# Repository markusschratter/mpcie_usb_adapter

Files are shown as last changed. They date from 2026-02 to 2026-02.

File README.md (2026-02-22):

# mPCIe USB Adapter

The mPCIe USB Adapter enables connecting mPCIe modules (WiFi, Bluetooth, GNSS, etc.) to a host system via USB 2.0. The board features power regulation from 5V to 3.3V, comprehensive ESD protection on USB and signal lines, and RF connectors for antenna connections. Status LEDs provide visual feedback for power indication.

- mPCIe connector for module connection
- USB 2.0 Type-C connector for host connectivity
- 3.3V voltage regulator (LD1117S33TR) for power regulation
- ESD protection diodes for USB and signal lines
- Status LEDs (Kingbright AA4040SURSK) for power indication
- SMA connectors for RF/antenna connections
- Coaxial connectors for additional RF connections

## Overview

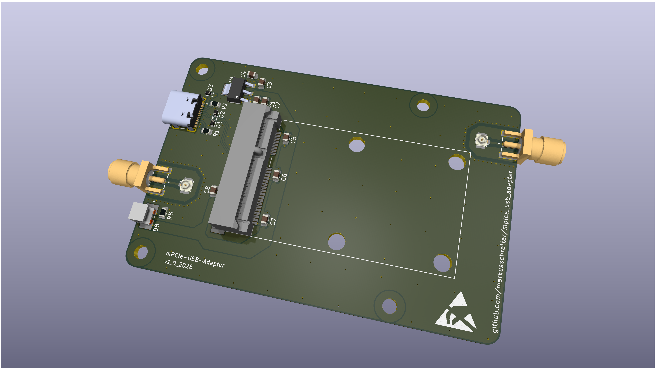
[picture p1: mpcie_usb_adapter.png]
mPCIe USB Adapter


The mPCIe USB Adapter board allows connecting mPCIe modules (such as WiFi, Bluetooth, or GNSS modules) to a host system via USB.

| Parameter | Value |
|---|---|
| Input Voltage | 5V DC (via USB) |
| Output Voltage | 3.3V DC (regulated) |
| USB Standard | USB 2.0 Type-C |
| Connector Type | mPCIe (full-size) |
| RF Connectors | 2x SMA, 2x Coaxial |

## Project Structure

```
mpcie_usb_adapter/
├── mpcie_usb_adapter.kicad_sch
├── mpcie_usb_adapter.kicad_pcb
├── mpcie_usb_adapter.kicad_pro
├── mpcie_usb_adapter.png
└── 3dmodels/                 # 3D models for components
    ├── mpcie_usb_adapter.step
    └── mpcie_usb_adapter.stl
```

## Components

| Component | Qty | Part Number | Description |
|---|-----|---|---|
| mPCIe Connector | 1 | [MM60-52B1-G1-R850](https://www.jae.com/de/connectors/series/detail/product/id=68908) ([Mouser](https://www.mouser.at/ProductDetail/JAE-Electronics/MM60-52B1-G1-R850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)) | mPCIe full-size connector |
| USB Connector | 1 | [USB4105-GF-A](https://gct.co/connector/usb4105) ([Mouser](https://www.mouser.at/ProductDetail/GCT/USB4105-GF-A?qs=KUoIvG%2F9IlY%2FMLlBMpStpA%3D%3D)) | USB 2.0 Type-C connector |
| Voltage Regulator | 1 | [LD1117S33TR](https://www.st.com/resource/en/datasheet/ld1117.pdf) ([Mouser](https://www.mouser.at/ProductDetail/STMicroelectronics/LD1117S33TR?qs=edoyzKMbmhntQZx4BFmoqw%3D%3D)) | 3.3V LDO regulator |
| SMA Connector | 2 | [SMA-J-P-H-ST-EM1](https://www.samtec.com/de/products/sma-j-p-h-st-em1) ([Mouser](https://www.mouser.at/ProductDetail/Samtec/SMA-J-P-H-ST-EM1?qs=92ilVni64gwBP41DrnuA8Q%3D%3D)) | SMA RF connector (Samtec) |
| UFL Connector | 2 | [U.FL-R-SMT-110](https://4donline.ihs.com/images/VipMasterIC/IC/HIRO/HIROS10696/HIROS08829-1.pdf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) ([Mouser](https://www.mouser.at/ProductDetail/Hirose-Connector/U.FL-R-SMT-110?qs=kL1ClTr6oBoOdtqlGQpQrQ%3D%3D)) | UFL coaxial RF connector (Hirose) |
| LED | 1 | [AA4040SURSK](https://www.kingbrightusa.com/images/catalog/spec/aa4040sursk.pdf) ([Mouser](https://www.mouser.com/ProductDetail/Kingbright/AA4040SURSK)) | Status LED (Kingbright) |
| ESD Protection | 2 | ESD321 | ESD protection diode |
| ESD Protection | 1 | ESD441 | ESD protection diode |
| Resistors (5.1kΩ) | 2 | R_0805_2012Metric | LED current limiting |
| Resistor (750Ω) | 1 | R_0805_2012Metric | Current limiting |
| Capacitors (100nF) | 6 | C_0805_2012Metric | Decoupling capacitors |
| Capacitors (10µF) | 2 | C_0805_2012Metric | Filtering capacitors |

## Design Files

All design files are in KiCad 9.0 format (`.kicad_sch`, `.kicad_pcb`, `.kicad_pro`). 3D STEP and STL models of the board and components are included in the `3dmodels/` directory.

**3D Board Models:**
- [STEP file](3dmodels/mpcie_usb_adapter.step) - 3D model for mechanical design
- [STL file](3dmodels/mpcie_usb_adapter.stl) - 3D model for 3D printing

**Assembly Notes**: Ensure proper ESD handling during assembly, verify LED polarity, use appropriate USB cable specifications, follow RF connector assembly guidelines.

## Acknowledgments

Thanks to **Matteo Valentini** for review and modifications.

## License

Licensed under the Apache License, Version 2.0. See [LICENSE](LICENSE) file for details.

## Contributing

Contributions are welcome! Please feel free to submit issues or pull requests.

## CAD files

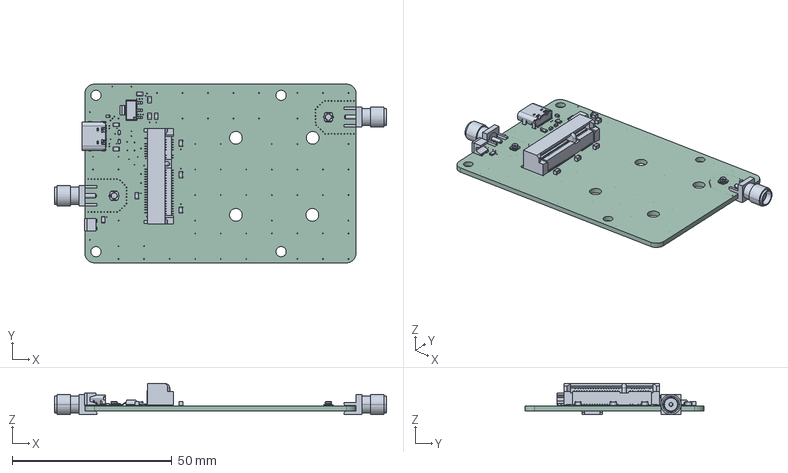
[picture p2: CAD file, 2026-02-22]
3dmodels/mpcie_usb_adapter.step
104.0 x 56.0 x 9.75 mm
LD1117S33TR
SMA-J-P-H-ST-EM1--3DModel-STEP-269445 x 2
C_0805_2012Metric x 8
U.FL_Hirose_U.FL-R-SMT-1_Vertical x 2
D_SOD-523 x 3
R_0805_2012Metric x 3
Prawa noga
Lewa noga
Tył
Front
USB4105GFA_USB4105GFA
mpcie_usb_adapter_PCB

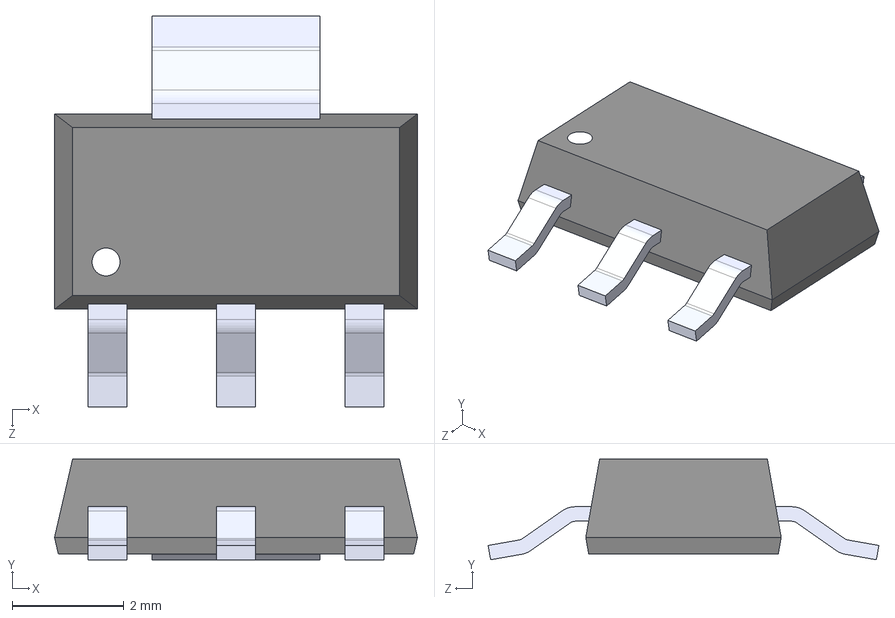
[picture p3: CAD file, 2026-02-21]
3dmodels/LD1117S33TR.step
6.50 x 1.80 x 7.00 mm

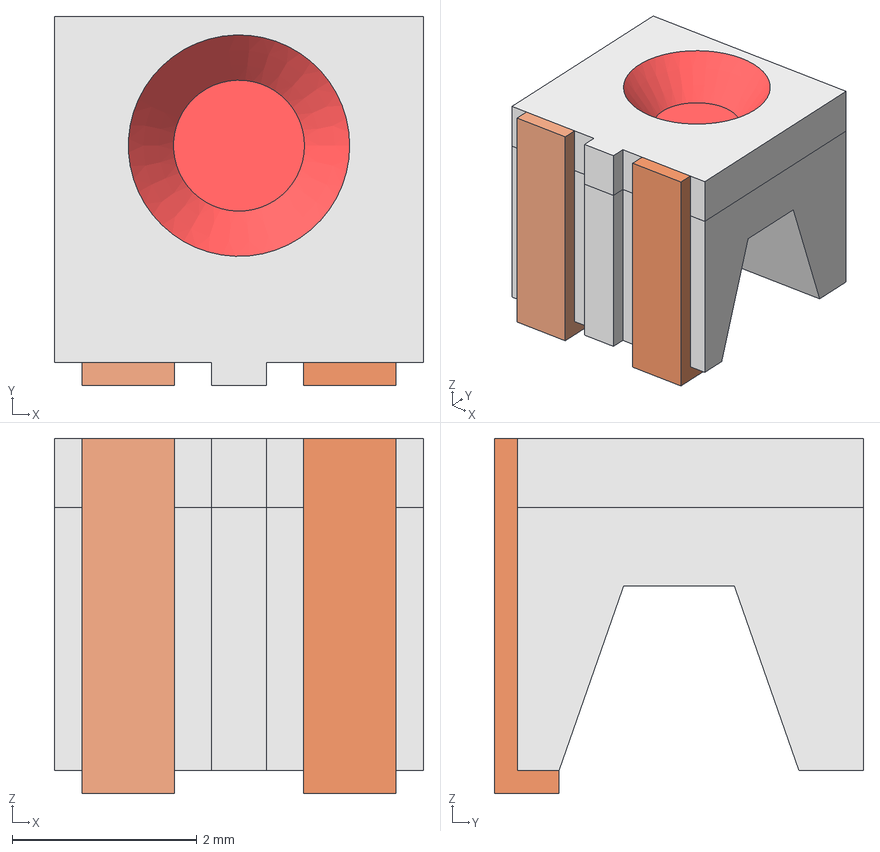
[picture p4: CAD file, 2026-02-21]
3dmodels/KA-4040SURSK.step
4.00 x 4.00 x 3.85 mm
Prawa noga
Lewa noga
Tył
Front

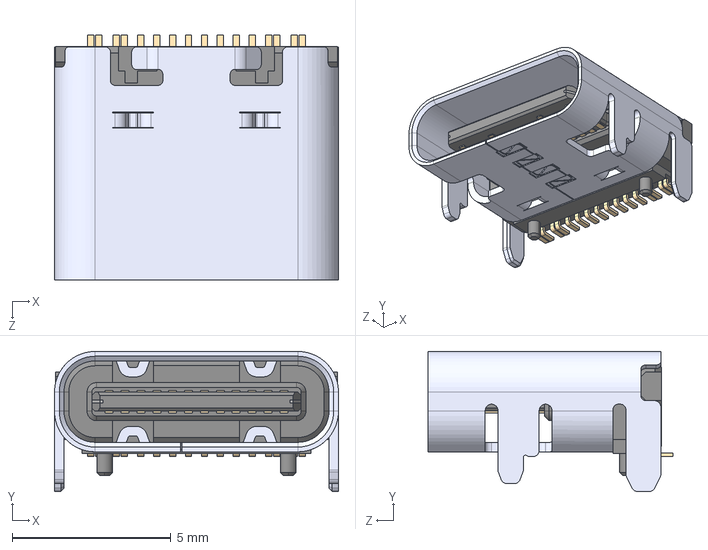
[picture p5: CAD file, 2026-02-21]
3dmodels/USB4105GFA--3DModel-STEP-510211.step
8.94 x 4.41 x 7.71 mm

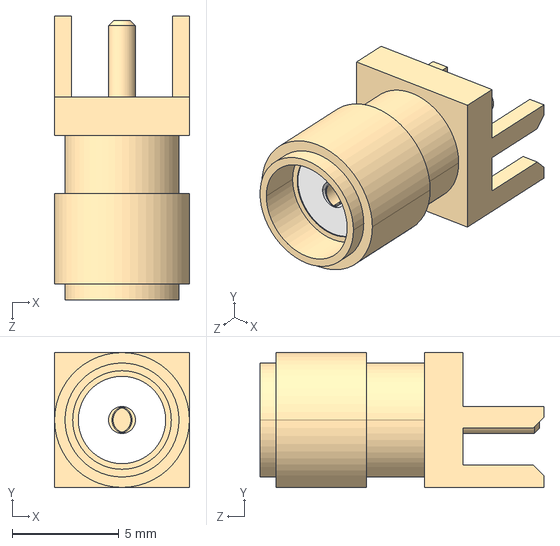
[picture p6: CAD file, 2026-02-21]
3dmodels/SMA-J-P-H-ST-EM1--3DModel-STEP-269445.step
6.35 x 6.35 x 13.3 mm

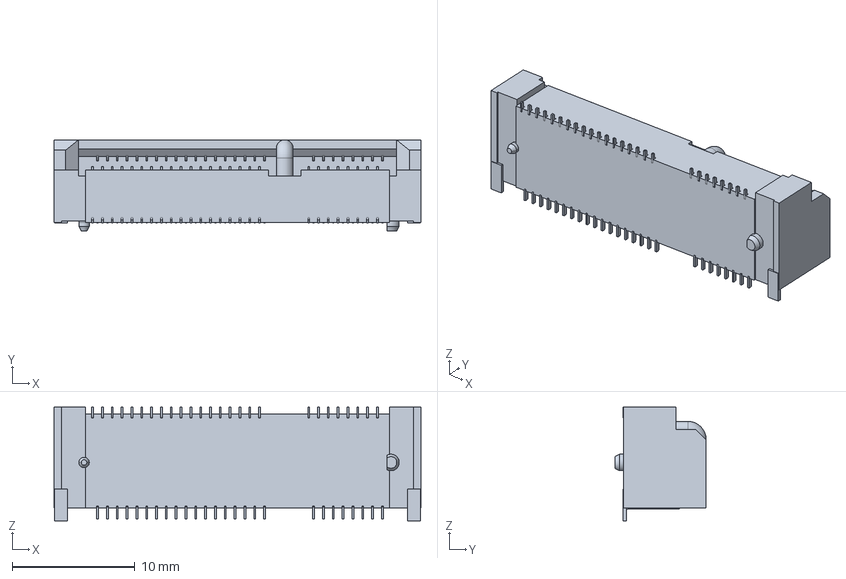
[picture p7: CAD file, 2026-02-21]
3dmodels/2041262-1.step
29.9 x 7.45 x 9.25 mm

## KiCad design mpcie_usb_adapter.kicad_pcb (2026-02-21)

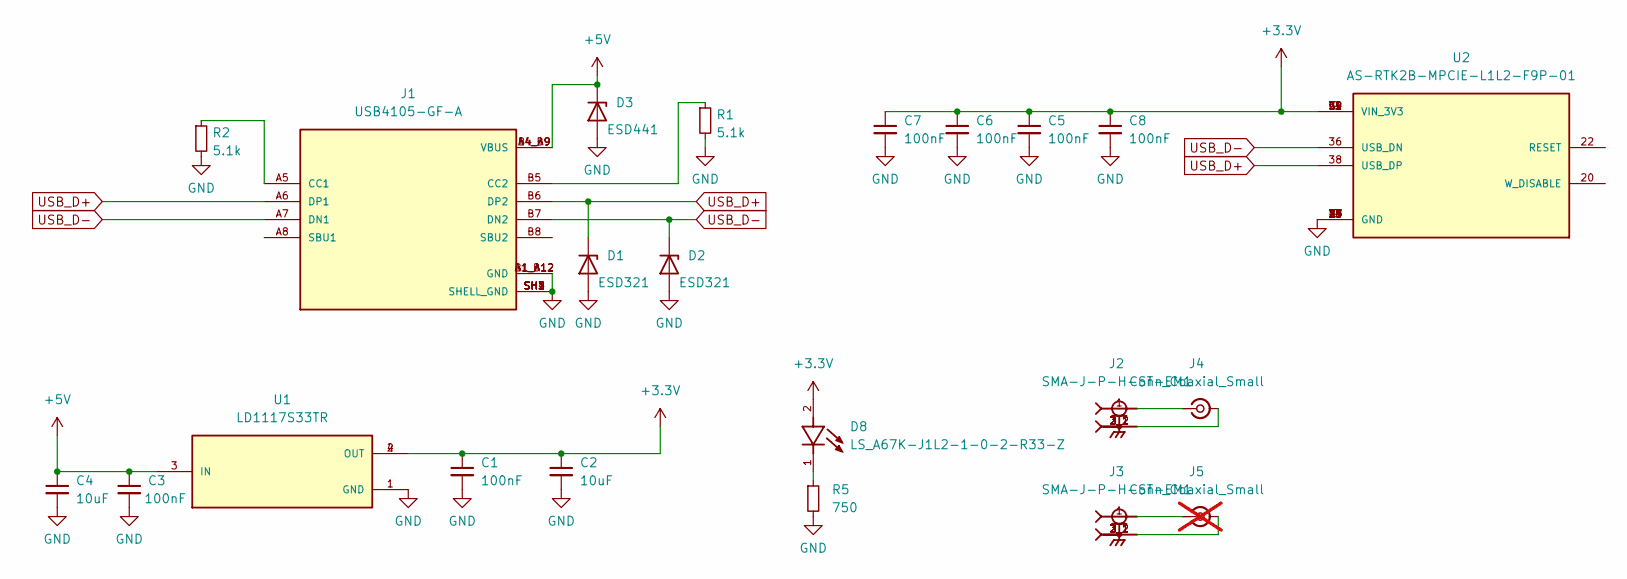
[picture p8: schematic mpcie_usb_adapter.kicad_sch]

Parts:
C1, C3, C5, C6, C7, C8: 100nF; C_0805_2012Metric
C2, C4: 10uF; C_0805_2012Metric
D1, D2: ESD321; D_SOD-523
D3: ESD441; D_SOD-523
D8: LS_A67K-J1L2-1-0-2-R33-Z; LED_LS_A67K-J1L2-1-0-2-R33-Z; PARTREV 1.5
J1: USB4105-GF-A; GCT_USB4105-GF-A; PARTREV B4
J2, J3: SMA-J-P-H-ST-EM1; SAMTEC_SMA-J-P-H-ST-EM1; PARTREV G
J4: Conn_Coaxial_Small; U.FL_Hirose_U.FL-R-SMT-1_Vertical
J5: Conn_Coaxial_Small; U.FL_Hirose_U.FL-R-SMT-1_Vertical; not fitted
R1, R2: 5.1k; R_0805_2012Metric
R5: 750; R_0805_2012Metric
U1: LD1117S33TR; SOT230P700X180-4N
U2: AS-RTK2B-MPCIE-L1L2-F9P-01; MODULE_AS-RTK2B-MPCIE-L1L2-F9P-01; PARTREV D

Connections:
+3.3V: C1.1, C2.1, C5.1, C6.1, C7.1, C8.1, D8.2, U1.2 (OUT), U1.4 (OUT), U2.2 (VIN_3V3), U2.24 (VIN_3V3), U2.39 (VIN_3V3), U2.41 (VIN_3V3), U2.52 (VIN_3V3)
+5V: C3.1, C4.1, D3.1 (K), J1.A4_B9 (VBUS), J1.B4_A9 (VBUS), U1.3 (IN)
GND: C1.2, C2.2, C3.2, C4.2, C5.2, C6.2, C7.2, C8.2, D1.2 (A), D2.2 (A), D3.2 (A), J1.A1_B12 (GND), J1.B1_A12 (GND), J1.SH1 (SHELL_GND), J1.SH2 (SHELL_GND), J1.SH3 (SHELL_GND), J1.SH4 (SHELL_GND), R1.2, R2.2, R5.2, U1.1 (GND), U2.9 (GND), U2.15 (GND), U2.21 (GND), U2.27 (GND), U2.29 (GND), U2.35 (GND), U2.37 (GND), U2.43 (GND)
unnamed: D8.1, R5.1
unnamed: J1.A5 (CC1), R2.1
unnamed: J1.B5 (CC2), R1.1
unnamed: J2.2_1, J2.2_2, J2.3_1, J2.3_2, J4.2 (Ext)
unnamed: J2.1, J4.1 (In)
unnamed: J3.2_1, J3.2_2, J3.3_1, J3.3_2, J5.2 (Ext)
unnamed: J3.1, J5.1 (In)
USB_D+: D1.1 (K), J1.A6 (DP1), J1.B6 (DP2), U2.38 (USB_DP)
USB_D-: D2.1 (K), J1.A7 (DN1), J1.B7 (DN2), U2.36 (USB_DN)

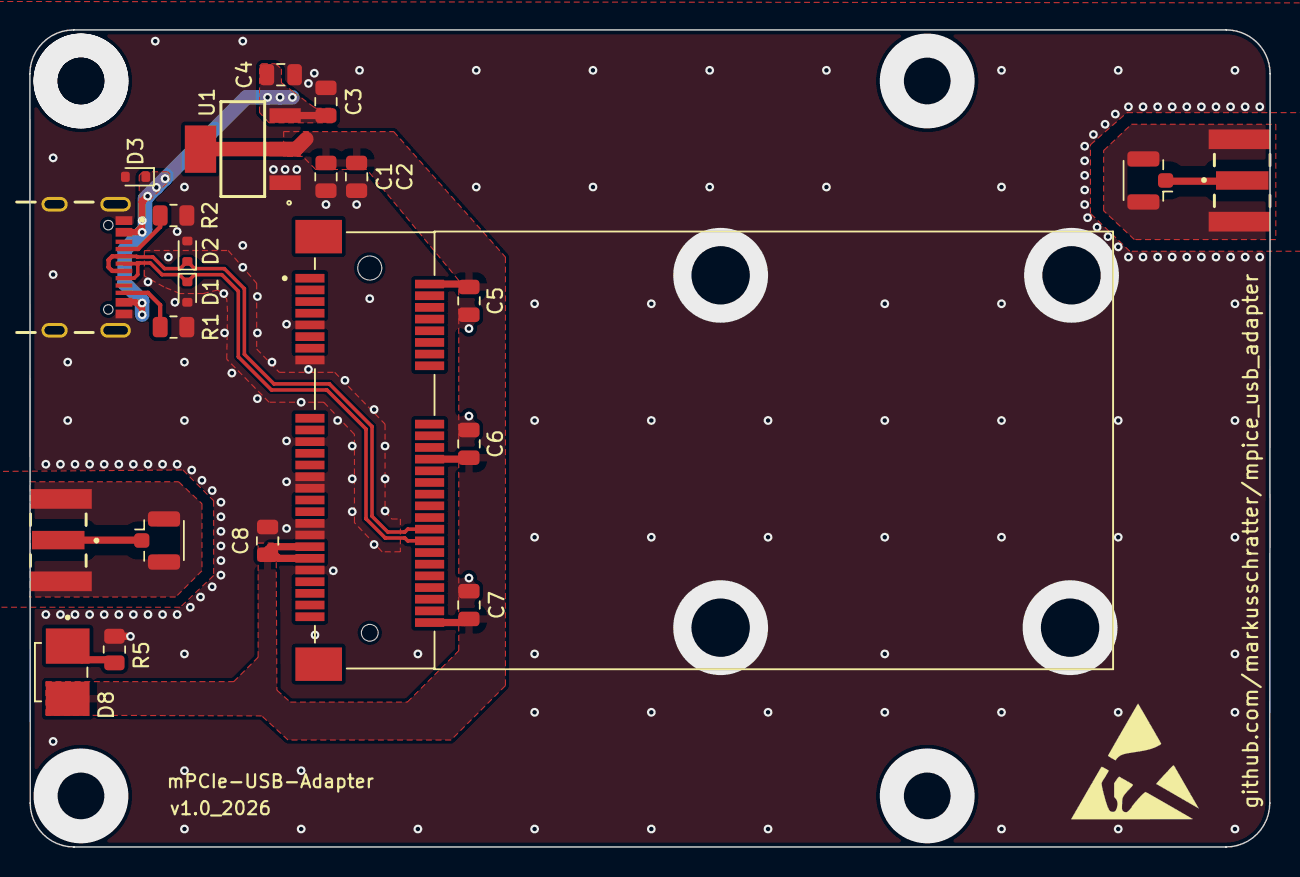
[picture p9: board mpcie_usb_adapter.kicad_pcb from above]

Board: 2 copper layers, 85.0 x 56.0 mm, 22 parts (0 on the bottom side), 12 nets.

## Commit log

2026-02-21 integrated updates from Matteo and added 3d models
    [2041262-1.step, KA-4040SURSK.step, LD1117S33TR.step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]
2026-02-22 added README.md and 3d models of the board (step,stl)
    [mpcie_usb_adapter.step]
